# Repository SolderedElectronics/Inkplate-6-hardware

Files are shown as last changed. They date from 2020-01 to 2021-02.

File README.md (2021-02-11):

# Inkplate 6 Open Source Hardware files



Open Source Hardware (OSH) files for e-paper display Inkplate 6 can be found in this repo. Inkplate 6 is a powerful, Wi-Fi enabled ESP32 based six-inch e-paper display – recycled from a Kindle e-reader. Its main feature is simplicity. Just plug in a USB cable, open Arduino IDE, and change the contents of the screen with few lines of code. Learn more about Inkplate 6 on [Crowd Supply](https://www.crowdsupply.com/e-radionica/inkplate-6) or [official website](https://inkplate.io).

### Versions:
- v1.0. first, original version shipped to backers in 2020 and manufactured until January 2021.

### Misc
Inkplate 6 is available for purchase via:
- [e-radionica.com](https://e-radionica.com/en/inkplate.html)
- [Crowd Supply](https://www.crowdsupply.com/e-radionica/inkplate-6)
- [Mouser](https://hr.mouser.com/Search/Refine?Keyword=inkplate)
- [Pimoroni](https://shop.pimoroni.com/products/inkplate-6)

For all questions and issues, please open an issue or thread on [our forums](http://forum.e-radionica.com/en/).
For sales & collaboration, please reach us via [e-mail](mailto:kontakt@e-radionica.com).

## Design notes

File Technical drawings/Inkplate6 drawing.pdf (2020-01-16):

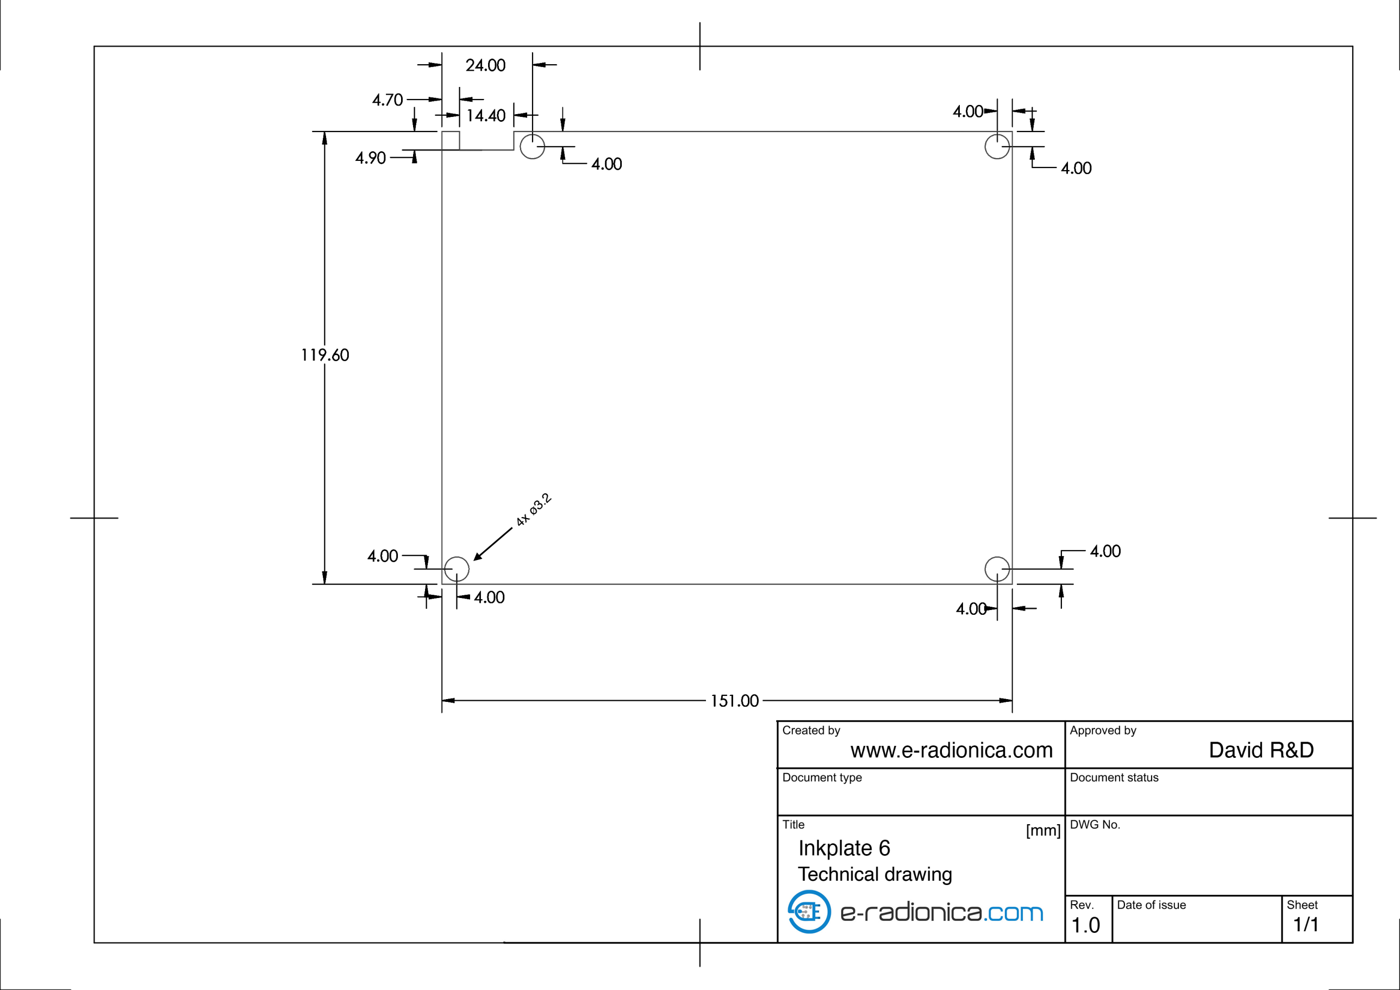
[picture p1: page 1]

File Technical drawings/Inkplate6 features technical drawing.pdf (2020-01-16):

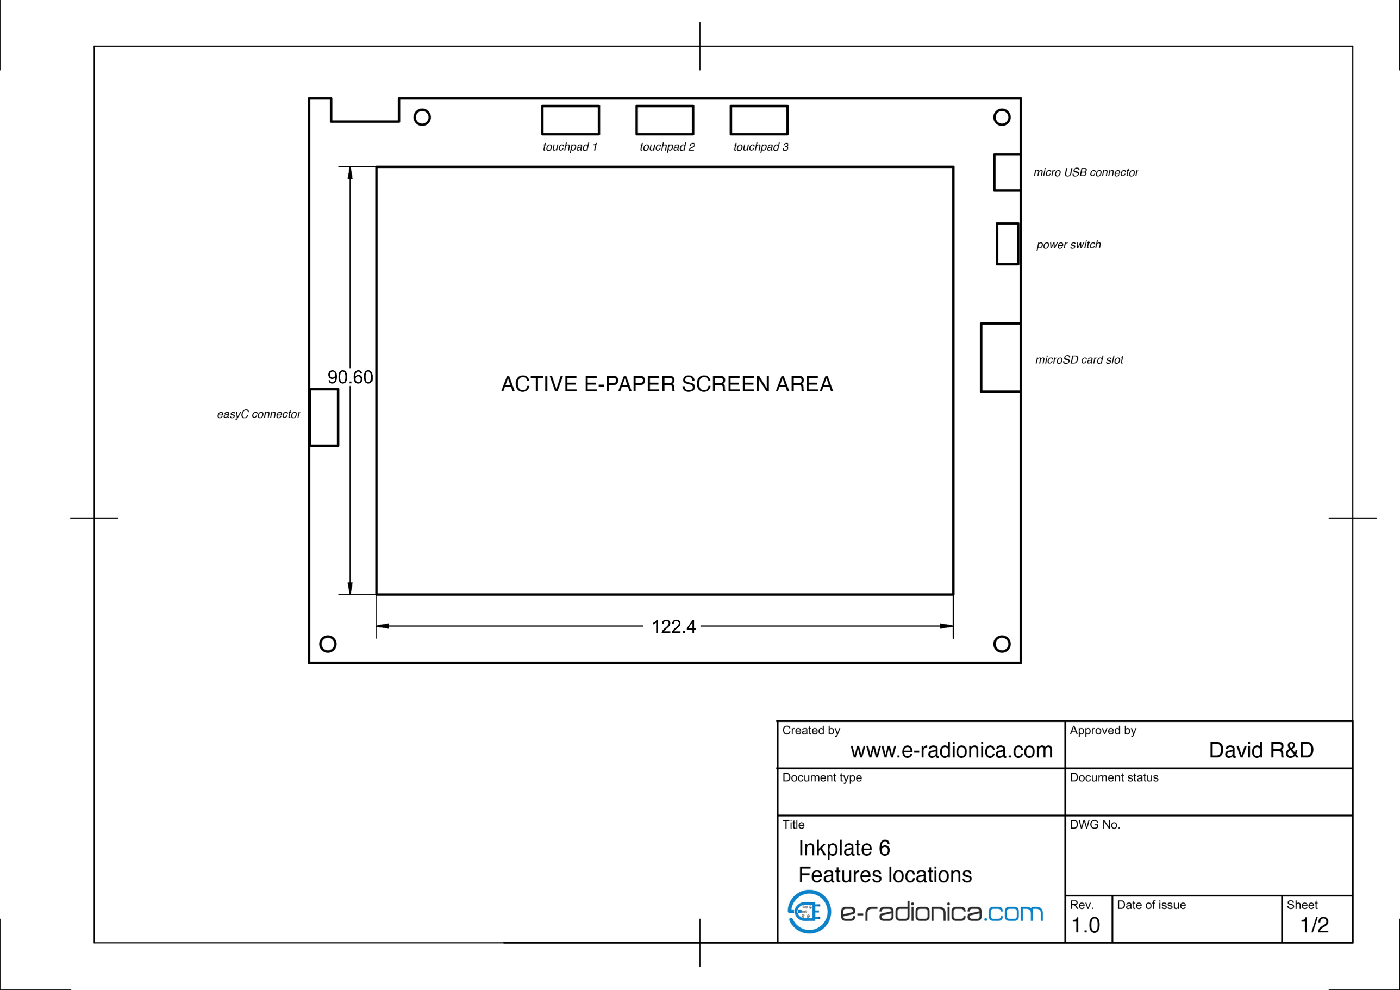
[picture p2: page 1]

122.4

90.60

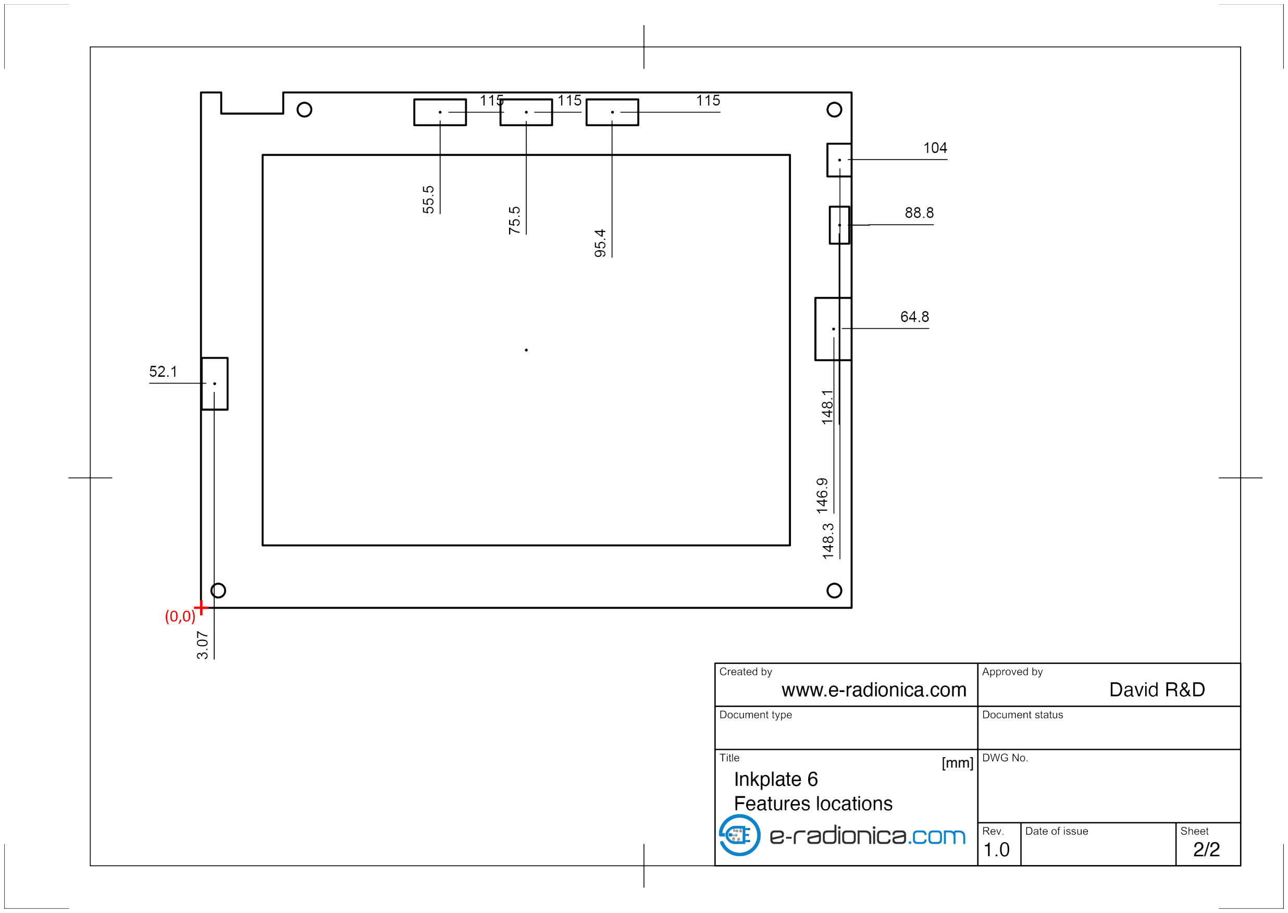
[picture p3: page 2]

(0,0)

+

[mm]

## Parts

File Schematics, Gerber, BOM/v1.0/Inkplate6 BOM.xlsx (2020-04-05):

Comment | Description | Designator | Footprint | LibRef | Quantity | Manufacturer PN
4u7-TMK212AB7475KG-T | CAPACITOR 0805 CERAMIC | C1, C2, C3, C4, C5, C6, C7, C10, C11, C12 | 0805C-GENERIC | 0805C-4U7-25V-X5R-TDK | 10 | TMK212AB7475KG-T
10uF-GRM188R61E106KA73J | CAPACITOR 0603 CERAMIC | C8, C9, C13 | 0603C-GENERIC | 0603C-10UF-10V-X5R-TDK | 3 | GRM188R61E106KA73J
100nF - AC0603KRX7R8BB104 | CAPACITOR 0603 CERAMIC | C14, C15 | 0603C-GENERIC | 0603C-100NF-25V-X7R-TDK | 2 | AC0603KRX7R8BB104
10nF-AC0603KRX7R8BB103 | CAPACITOR 0603 CERAMIC | C16, C19 | 0603C-GENERIC | 0603C-10NF-50V-X7R-MUR | 2 | AC0603KRX7R8BB103
2u2-GRM188R61E225MA12D | CAPACITOR 0603 CERAMIC | C17, C18 | 0603C-2U2 | 0603C-2U2-10V-X5R-TDK | 2 | GRM188R61E225MA12D
10UF | GENERIC CAPACITOR NON POLARISED 1206 | C20 | 1206C-GENERIC | 1206C-10U-35V-X7R | 1 | GENERIC
2u2 | CAPACITOR 0603 CERAMIC | C21, C27, C28, C39, C45 | 0603C-2U2 | 0603C-2U2-10V-X5R-TDK, 0603C-2U2-10V-X5R-TDK, 0603C-2U2-10V-X5R-TDK, 0603C-2U2-6V3-X5R-MUR, 0603C-2U2-10V-X5R-TDK | 5 | GENERIC
100nF | CAPACITOR 0603 CERAMIC | C22, C23, C24, C25, C26, C29, C30, C31, C32, C33, C34, C35, C40, C41, C49 | 0603C-GENERIC | 0603C-100NF-25V-X7R-TDK | 15 | GENERIC
27pF | CAPACITOR 0603 CERAMIC | C36, C37, C38 | 0603C-GENERIC | 0603C-27pF | 3 | GENERIC
68uF/6.3V | TANTALUM 3528 CAPACITOR | C42, C43 | C3528 | CAP3528 | 2 | GENERIC
100pF | CAPACITOR 0603 CERAMIC | C44 | 0603C-GENERIC | 0603C-100PF-50V-NP0-AVX | 1 | GENERIC
22pF | CAPACITOR 0603 CERAMIC | C46, C47 | 0603C-GENERIC | 0603C-22PF-50V-C0G-PAN | 2 | GENERIC
easyC | EASYC ECOSYSTEM JST CONNECTOR SMD FEMALE VERTICAL | CON1 | easyC | easyC | 1 | GENERIC
2PIN JST CONNECTOR | STANDARD LITHIUM BATTERY JST CONNECTOR | CON2 | JST_SMD_2P | JST_SMD_2P | 1 | GENERIC
USB_CONN | U-F-M5DD-Y-L | CON3 | USB_CONN | USB_CONN | 1 | U-F-M5DD-Y-L
BAS3010S-02LRHE6327 | DIODE SCHOTTKY 30V 1A TSLP-2 | D1, D2 | BAS3010S-02LRHE6327 | BAS3010S-02LRHE6327 | 2 | BAS3010S-02LRHE6327
BAT54-SOT23 | SINGLE SHOTTKY DIODE | D3, D4, D5, D6 | SOT23-123 | BAT54-SOT23 | 4 | BAT54
BAT20 | Schottky Diode SOD323 1A 23V | D8 | SOD323 | BAT20-SOD323 | 1 | BAT20J
AXT334124 | SMD CONNECTOR | DISP1 | AXT334124 | AXT334124 | 1 | AXT334124
GENERIC 500mA | GENERIC FUSE | F1 |  | FUSE-GENERIC | 1 | JK-NSMD050-13.2V
TPS65186 | IC PWR MGMT E INK 48VQFN | IC1 | TPS65186_QFN_48 | TPS65186RGZR | 1 | TPS65186RGZR
ESP32 WROVER | ESP32 WROVER WIFI MODULE | IC2 | ESP32_WROVER | ESP32WROVER | 1 | ESP32-WROVER
MCP23017 | I2C I/O Expander | IC3 | SOP28 | MCP23017 | 1 | MCP23017/SS
MCP73831 | LITHIUM BATTERY CHARGER | IC4 | SOT23-5_MCP | MCP73831 | 1 | MCP73831T-2ATI/OT
TTP223 | CAPACITIVE TOUCH CONTROLLER | IC6, IC7, IC8 | SOT95P285X126-6N_TTP223 | TTP223 | 3 | TTP223E-BA6
TPS3840PL27DBVR | RESET CONTROLLER | IC9 | TPS3840PH30DBVR | TPS3840PH30DBVR | 1 | TPS3840PL27DBVR
HYC77-TF09-200 | MICROSD CARD SLOT | K39 | HYC77-TF09-200 | HYC77-TF09-200 | 1 | HYC77-TF09-200
4.7uH | Inductor Power Chip Shielded Wirewound 4.7uH 20% 1MHz Ferrite 1.7A 96mOhm DCR 1515 Embossed T/R | L1 | LQH44PN4R7MP0_Inductor | LQH44PN4R7MP0L | 1 | LQH44PN4R7MP0L
2.2uH | FIXED IND 2.2UH 1.2A 108 MOHM | L2 | NR4012T2R2M_Fixed Inductor | NR4012T2R2M | 1 | NR4012T2R2M
LED0603 | LED 0603 SINGLE COLOR | LED1 | LED0603 | LED0603 | 1 | GENERIC
MTA50P01SN3 | P CHANNEL MOSFET - MTA50P01SN3 | Q1 | SOT23-GDS | BSS84 | 1 | MTA50P01SN3
MMBT2222 | MMBT2222 | Q2, Q3 | SOT95P237X110-3N | MMBT2222 | 2 | MMBT2222
CJ3407 | P CHANNEL MOSFET | Q4 | SOT23-GDS | BSS84 | 1 | GENERIC
NTC-NCP18X103F03RB | NCP18X103F03RB | R1 | 0603R-GENERIC | R0603-GENERIC | 1 | NCP18X103F03RB
43k-RC0603FR-0743KL | RC0603FR-0743KL | R2 | 0603R-GENERIC | R0603-GENERIC | 1 | RC0603FR-0743KL
1M | GENERIC RESISTOR 0603 | R3, R4 | 0603R-GENERIC | 0603R-1M | 2 | GENERIC
52k3-RC0603FR-0752K3L | RC0603FR-0752K3L | R5 | 0603R-GENERIC | R0603-GENERIC | 1 | RC0603FR-0752K3L
47k5-RC0603FR-0747K5L | RC0603FR-0747K5L | R6 | 0603R-GENERIC | R0603-GENERIC | 1 | RC0603FR-0747K5L
10K | GENERIC RESISTOR 0603 | R7, R8, R10, R11 | 0603R-10K | 0603R-10K | 4 | GENERIC
1K | GENERIC RESISTOR 0603 | R9, R12, R14, R16, R21, R22, R23, R27 | 0603R-1k | 0603R-1K | 8 | GENERIC
2K49 | GENERIC RESISTOR 0603 | R15 | 0603R-GENERIC | 0603R-2K49 | 1 | GENERIC
100K | GENERIC RESISTOR 0603 | R17, R19, R20 | 0603R-100K | 0603R-100K | 3 | GENERIC
0R - DNP | GENERIC JUMPER 0603 | R18 | 0603R-0R | 0603R-0R | 1 | GENERIC
510k | GENERIC RESISTOR 0603 | R24, R25 | 0603R-GENERIC | R0603-GENERIC | 2 | GENERIC
SMD Pushbutton | SMD PUSHBUTTON | SW1 | Pushbutton4x4 | TACT_SMD_SW | 1 | GENERIC
SPDT SWITCH THT | SPDT THT SWITCH 2A | SW2 | SPDT_SW | ONOFF_SW | 1 | 1
DMG2301L | P CHANNEL MOSFET | T1 | SOT90P240X110-3N | DMG2301L | 1 | DMG2301L-7
CH340G | USB-UART converter CH340G | U1 | SOP16 | CH340G | 1 | CH340G
TPS7A2633DRVR | ULTRA-LOW IQ VOLTAGE REGULATOR 500MA | U2 | TPS7A2633DRVR | TPS7A2633DRVR | 1 | TPS7A2633DRVR
12MHz | SMD CRYSTAL 12MHZ 3225 | Y1 | 3225_crystal | 3225-crystal | 1 | S3212000201080
ED060SC7 | E-PAPER DISPLAY 6INCH | - | ED060SC7 | ED060SC7 | 1 | ED060SC7

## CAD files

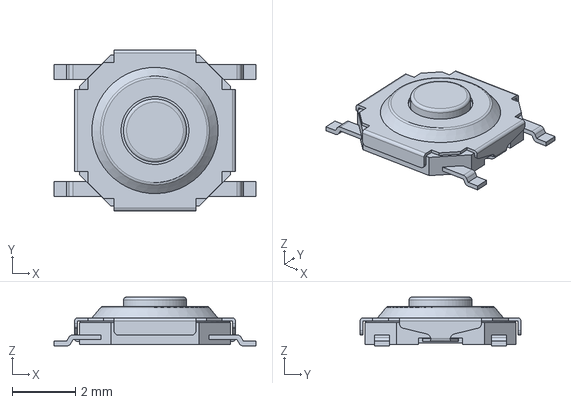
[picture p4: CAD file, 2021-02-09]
3D printable case/Guy's case/Electronics/KiCAD/Parts/3D/PTS526SK15SMTR2LFS.stp
6.40 x 5.10 x 1.55 mm

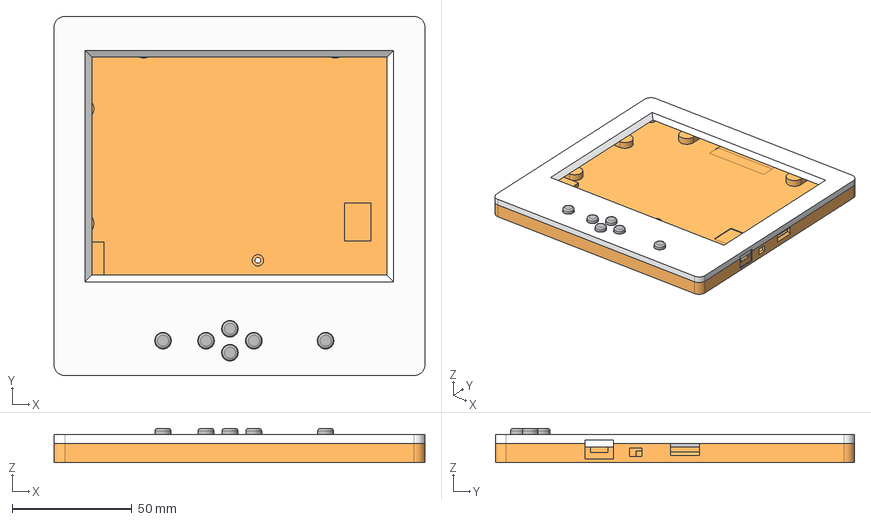
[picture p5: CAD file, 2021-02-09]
3D printable case/Guy's case/Mechanical CAD/Inkplate_6_Case_With_Mechanical_Buttons.step
155.2 x 150.2 x 14.3 mm
Inkplate_6_Case_Enlarged_Bottom
Button x 6
Inkplate_6_Case_Enlarged_Top
U1_1_601E0A63_5
U1_1_601E0A63
Pcb_dfda
U1_1_601E0A63_3
U1_1_601E0A63_4
U1_1_601E0A63_2
U1_1_601E0A63_1

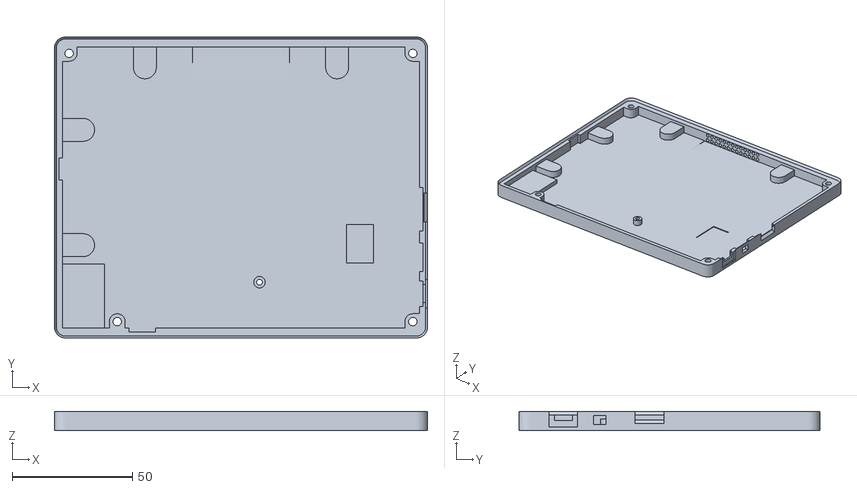
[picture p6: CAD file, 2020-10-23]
3D printable case/Original case/Inkplate_6_Case_Bottom.stl
155.2 x 125.2 x 8.00

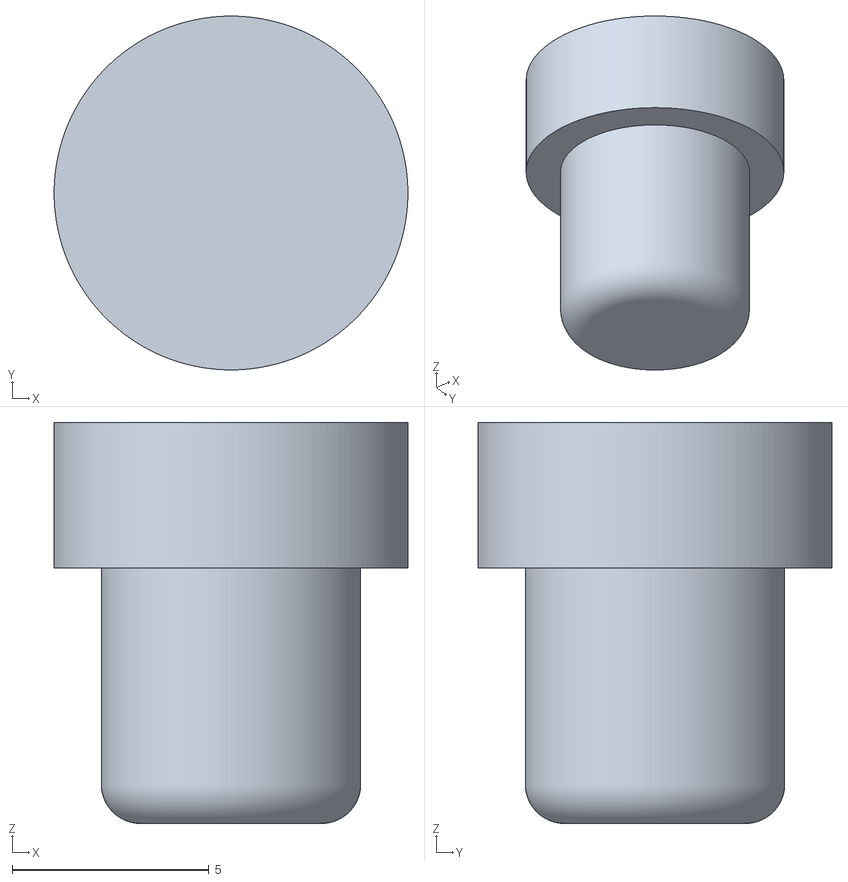
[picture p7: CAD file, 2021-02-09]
3D printable case/Guy's case/Mechanical CAD/Inkplate_6_Button.stl
9.00 x 9.00 x 10.2

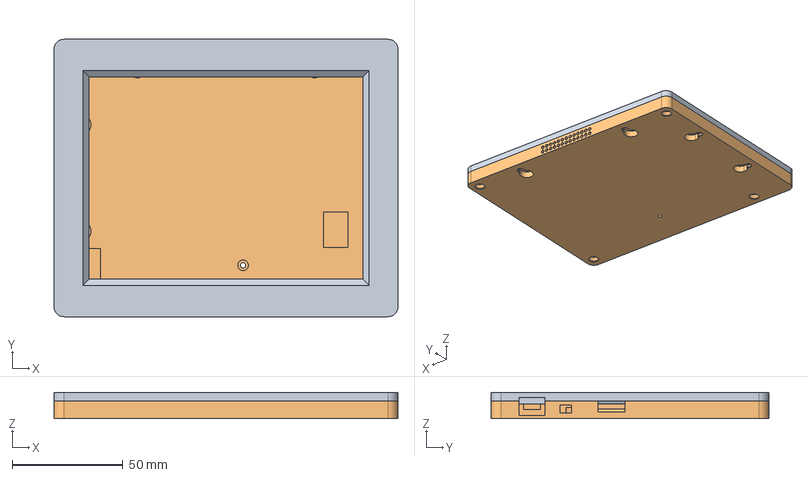
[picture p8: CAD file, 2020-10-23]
3D printable case/Original case/Inkplate_6_Case_v1_5.step
155.2 x 125.2 x 11.8 mm
Inkplate_6_Case_Top
Inkplate_6_Case_Bottom

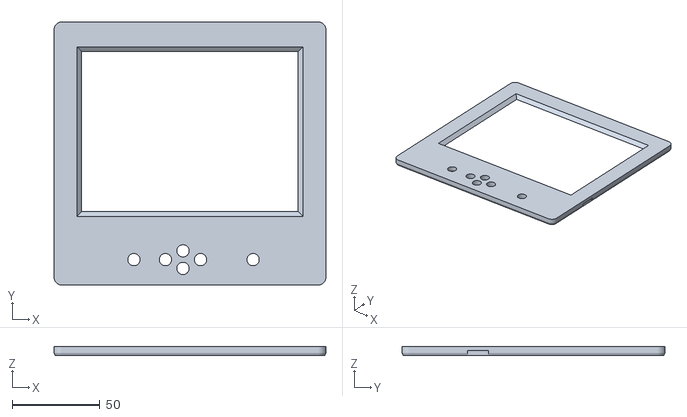
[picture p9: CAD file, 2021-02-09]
3D printable case/Guy's case/Mechanical CAD/Inkplate_6_Case_Enlarged_Top.stl
155.2 x 150.2 x 5.20

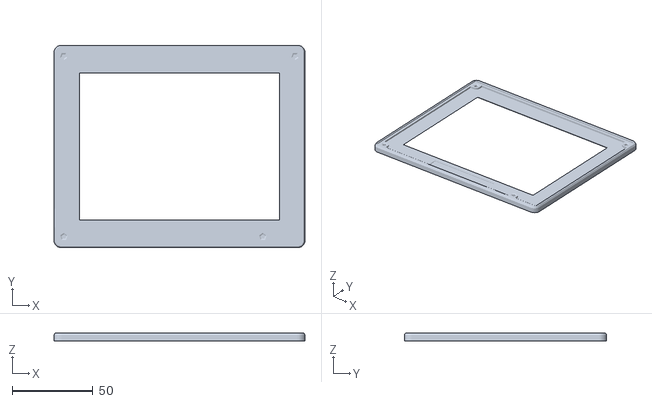
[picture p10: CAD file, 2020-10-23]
3D printable case/Original case/Inkplate_6_Case_Top.stl
155.2 x 125.2 x 5.20

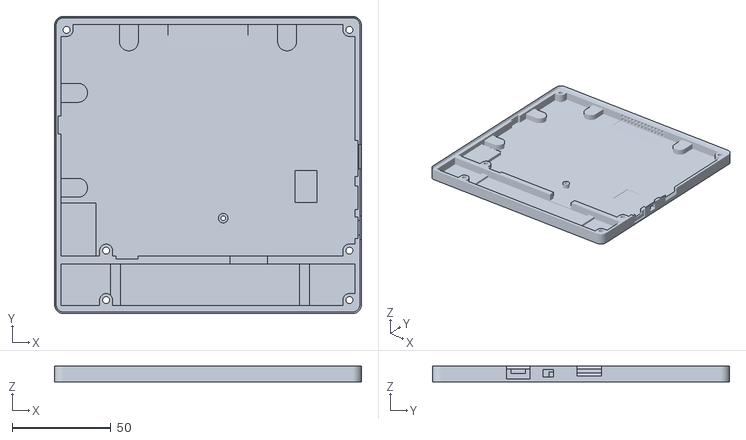
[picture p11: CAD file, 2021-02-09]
3D printable case/Guy's case/Mechanical CAD/Inkplate_6_Case_Enlarged_Bottom.stl
155.2 x 150.2 x 8.00

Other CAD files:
3D printable case/Inkplate_6_Case_v1_4.blend
3D printable case/Original case/Inkplate_6_Case_v1_5.f3d
3D printable case/Original case/OLD_Inkplate_6_Case_v1_4.blend

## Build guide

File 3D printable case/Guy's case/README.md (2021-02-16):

# InkPlate-6-Extended-Case

Find original Guy's work at [this repo](https://github.com/turgu1/InkPlate-6-Extended-Case).

This is a change to the current InkPlate-6 case to add a small electronic board with push buttons below the mainboard. To do it, I took the original design from e-Radionica and extended a side of it, so the original portion of the case remains unchanged. The `Mechanical CAD` folder contains the complete STEP format design as well as the STL files ready for 3D printing. The `Electronics` folder contains the Gerber files for the preparation of the pc-board, as well as the schematic in PDF. I have used **OnShape** and **KiCAD** to complete this project.

- For the STL files, dimensions are in millimeters. 
- Six buttons must be printed as well as the top and bottom casing. The buttons may have to be adjusted in size depending on the 3D printing results.
- The connection with the MCU23017 is done using wirewrap wires (or a flat cable) that are soldered at both ends using the following configuration (beware that the corresponding buttons numbers are inverted in the sequence):

```
   On the   |     On the     | Corresponding 
Buttons PCB | InkPlate Board |    Button
------------+----------------+---------------
            |                |
   Pin 1    |      GND       |
   Pin 2    |      GPB7      |      U6
   Pin 3    |      GPB6      |      U3
   Pin 4    |      GPB5      |      U5
   Pin 5    |      GPB4      |      U1
   Pin 6    |      GPB3      |      U4
   Pin 7    |      GPB2      |      U2
```

- The squared pad is pin 1.
- On the buttons' pc-board, there is no through-hole, just pads on the surface to solder the wires. This is to ensure that the board will remains flat at the bottom of it's location in the casing.
- The three touch pads on the InkPate-6 pc-board must be disabled, the corresponding signals from the MCU23017 must be diverted to the GPBx pin holes on the main pc-board. This is done by desoldering the current jumpers and soldering them back on the other side. They are located under the following labeling on the board: "Touch pads".
- The GPIOB I/O bits of the MCU23017 corresponding to the GPB2 through GPB7 pins must have their internal pull-up resistor enabled.
- The buttons' pc-board must be of a standard height (1.6 mm). This to ensure proper spacing for the printed buttons. The board must be 'glued' at the bottom of the main casing using two-sided scotch tape. An alternative would be using a very small amount of hot glue on the 4 corners on the top of the buttons' pc-board. This is to permit easy removal in case of problems. 
- The button switches' part number is C&K PTS526 SK15 SMTR2 LFS 5.2x5.2x1.5 mm. They are very common (For exemple, Mouser part # 611-PTS526SK15SMR2L, Digikey Part # CKN12221-1-ND, or other manufacturers equivalent). The 1.5 mm height is important to insure proper spacing for the printed buttons.

The original licensing from e-Radionica remains GPL-3 for their design as well as all supplied files in this project.

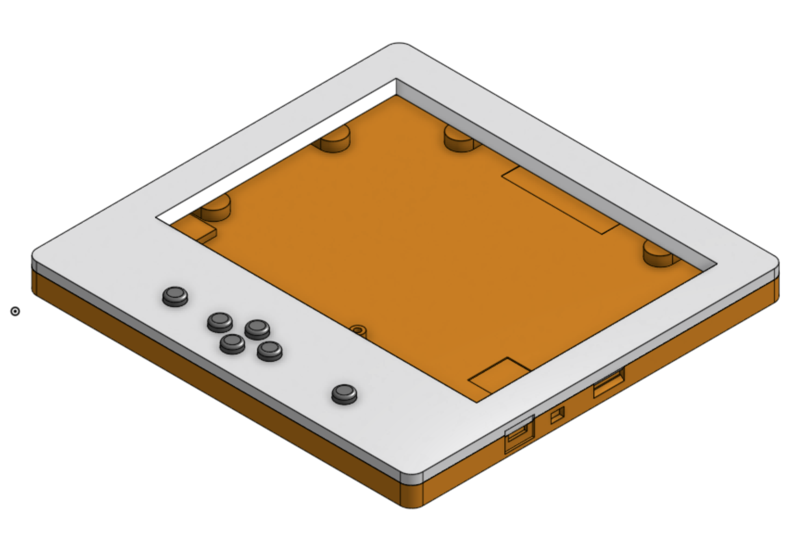
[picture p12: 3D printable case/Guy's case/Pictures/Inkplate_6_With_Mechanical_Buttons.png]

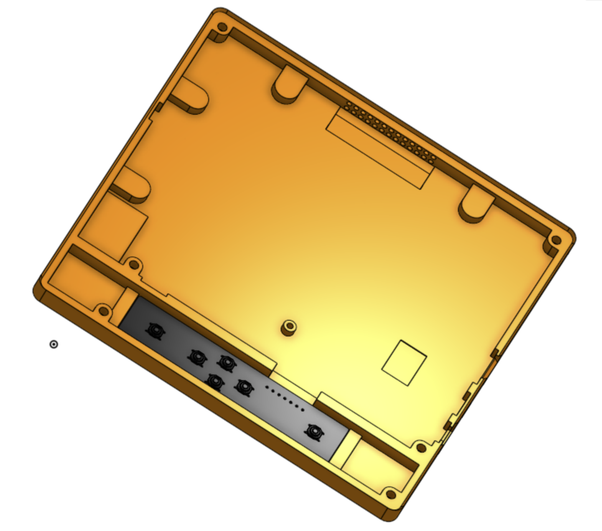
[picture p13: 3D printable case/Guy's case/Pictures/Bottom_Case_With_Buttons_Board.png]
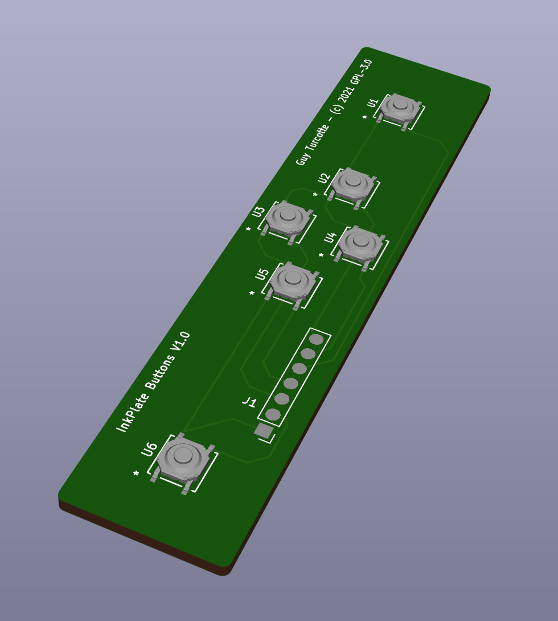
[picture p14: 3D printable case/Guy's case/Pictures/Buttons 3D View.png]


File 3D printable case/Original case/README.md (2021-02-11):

3D printable case. Printed in batches on Prusa MK3S(+) 3D printers, in PLA.

Screws: M3 x 10mm countersunk, 4 pieces

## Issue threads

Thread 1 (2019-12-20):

Feature request: 3D printable case

JustGitting, 2019-12-20:
Hi,

It is fantastic to see a free and open source e-reader using recycled parts. Well done!

Would you be able to add a basic 3D printable case design for Inkplate in the future?

Thanks!

davidzovko, 2019-12-22:
Thank you on praises, @JustGitting!

3D printable case is logical follow up, we will publish one on our crowdfunding campaign in the following weeks: https://www.crowdsupply.com/e-radionica/inkplate-6

.stl files will be added to this repo as well.

David

davidzovko, 2020-05-03:
Hey, files for the case has been added! We will update the 3D design file as it evolves.

Closed 2020-05-03.

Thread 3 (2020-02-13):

Sister project? The Open Book

JustGitting, 2020-02-13:
Hi,

It's exciting to see the Free-Software / Open Hardware movement gain momentum with the explicit aim of protecting our privacy.

I just found [The Open Book](https://github.com/joeycastillo/The-Open-Book)" project that is currently developing a open-source make it yourself e-reader. The specifications are lower, but the goals are just as high.

1) Would you be able to make a comparison between the Inkplate and The Open Book?

2) Would you consider helping each other as you both are working on essentially the same project? (I'm not affiliated, I just want both of your projects to succeed!)

Best wishes.

davidzovko, 2020-04-06:
Hey there, sorry for late reply!

The Open Book project is a great one. As my knowledge goes, it's made as open-source e-book reader. It has all you need to get started with e-book quickly, which Inkplate does not have. On the other hand, Inkplate has a simplicity to get you started with any kind of project which includes e-paper display, comparing to Open Book which is specialised.
So, it depends on the use case, but I see both product as a great contribution to open source community!

Of course, I have just sent a suggestion to the Open Book project owner. Let's see what he thinks :)

Thank you for the suggestion!
David

JustGitting, 2020-04-06:
No worries, I understand you and e-radioicacom have been busy!

Closed 2020-04-06.

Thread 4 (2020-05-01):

Idea: Type-C USB

craftbyte, 2020-05-01:
USB Type C connectors are being used more and more in the hardware industry (even RPi 4 has switched). It would be a logical idea for a new product like Inkplate to use USB-C instead of microUSB for longevity reasons (since unlike microUSB, with USB-C the cable deteriorates instead of the plug). Would it be possible to get an Inkplate v2 with a USB-C connector?

davidzovko, 2020-05-03:
Thanks for your suggestion, Anže. We agree and have already implemented USB-C for the future version.

Closed 2020-05-03.

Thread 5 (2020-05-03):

Please make actual source files available

sebastius, 2020-05-03:
Hi, this is not open-source hardware. I love the concept behind Inkplate and i'd love to contribute in the design. Sadly you've not published the actual source files, so i cannot contribute to your work. Please publish your sources, and also publish your iteration commits so we can see the design evolve and help out!

sebastius, 2020-05-09:
Oh another bit: you're not even including the component layout. So When you make these PCBs yourself, you have to reverse engineer the BOM+Schematic to figure out which bit goes where.

This is not open source hardware. Far from it even.

bbernhard, 2020-12-03:
I would also be interested in the eagle(?) files, in order to do some small modifications. Are there plans to opensource those files too? @davidzovko

dk5ra, 2020-12-05:
also interested! @davidzovko would be lovely

c5e3, 2020-12-05:
where is the pcb-layout source file of your cad software?

ziguana, 2021-05-29:
any updates on this?

SamantazFox, 2021-06-16:
Bump, I'd like to see the sources too!

Please provide Eagle/KiCad schematics and PCB design files, and BOM as CSV, not proprietary XLSX!

davidzovko, 2021-11-09:
Sorry not to publish the original source files. The files which we have are unavailable to be published publicly because of the software error which we have in Altium. We must redraw it in KiCad and afterwards, we will share it.

tiri, 2022-01-21:
I'd also like to see the source files publicly. Will they be released in the near future?

davidzovko, 2022-01-21:
Hi, yes, we are doing a redraw in KiCad and will publish them as soon as they are ready. We estimate about 2 months to get this done.

tiri, 2022-01-21:
Sounds awesome! Are you also going to publish also the 10" Inkplate source files?

davidzovko, 2022-01-22:
We are going to redo all board, incl. 10, in KiCAD and Soldered branding and release them here on our GitHub.

schroedi83, 2022-07-17:
Any update on this?

tommy-hartmann, 2023-01-16:
I bought the Inkplate6 just recently. I also printed the Case and and had to realize that it does not fit.
It would be nice to at least have a note in the Readme that there is a new version pf the board.

I am also interested which GPIO pin is used for the wakup button. Could we at least have a screenshot of the PCB Design?
Thanks!

c5e3, 2023-01-18:
i have the parts since more than 2 years, i think i'll just throw them away

ifadiga, 2023-01-22:
Hello,

Sorry for the problem with the wrong files for 3D model and schematics.

As David said before we working on new branding and doing all our boards in KiCad. We will be finished some of them for publishing on GitHub.

Next week we will have files for Inkplate 10. For the other Inkplate boards, I will put schematics and 3D models here in the comment until we publish all files.

ifadiga, 2023-01-25:
Hello
Here are the schematics for the four Inkplate that we finished. That are schematics for the new version of Inkplate. We fixed some things on it, but it is similar to the old one. If you need old schematics for some reason, tell me, and I can send you a PDF file. When asked for a schematic, write which GPIO expander you have on board and which branding (e-radionica or Soldered).

[Soldered Inkplate 10 Schematics.pdf](https://github.com/SolderedElectronics/Inkplate-6-hardware/files/10498529/Soldered.Inkplate.10.Schematics.pdf)
[Soldered Inkplate6 Schematics.pdf](https://github.com/SolderedElectronics/Inkplate-6-hardware/files/10498530/Soldered.Inkplate6.Schematics.pdf)
[Soldered Inkplate 6COLOR Schematics.pdf](https://github.com/SolderedElectronics/Inkplate-6-hardware/files/10498531/Soldered.Inkplate.6COLOR.Schematics.pdf)
[Soldered Inkplate 6PLUS Schematics.pdf](https://github.com/SolderedElectronics/Inkplate-6-hardware/files/10498532/Soldered.Inkplate.6PLUS.Schematics.pdf)

We are working on some details for the 3D case, and when finished, I will send it to you.

ifadiga, 2023-02-07:
We published files for our new Inkplate 10 board. You can see them on the [link ](url=https://github.com/SolderedElectronics/Soldered-Inkplate-10-hardware-design)

olalid, 2023-06-02:
I have just printed 3D case from files in the repository only to realise that it is not at all compatible with the board I just bought. The mechanical drawings are also not for the board I bought.
When can we expect correct drawings and/or 3D model to be available?

ifadiga, 2023-06-06:
Hello,
Sorry for the wrong file for Inkplate.

We working on the process for updating hardware files on GitHub and I hope that it will be done this week then all files will be available on our GitHub.

rosspointon, 2023-12-20:
@ifadiga - is there any update on the availability of the updated Inkplate 6 case 3d printable design? I just bought a replacement board without an enclosure thinking I could re-use my existing case but the hardware size/layout has changed.

rosspointon, 2023-12-20:
actually this library looks like it has the updated versions - its just quite hidden - https://github.com/SolderedElectronics/Soldered-Inkplate-6-hardware-design/

ifadiga, 2024-03-12:
Hello,

We've recently changed our storage system, and as a result, we don't yet have a repository for Inkplate 5. Due to these changes, I can't determine when the automatic repository setup will function as it did before.

For now, I'll send all the files in a zip file.
[Soldered Inkplate 5.zip](https://github.com/SolderedElectronics/Inkplate-6-hardware/files/14569012/Soldered.Inkplate.5.zip)

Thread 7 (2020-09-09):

Wifi on battery power not working

tobias--, 2020-09-09:
I am experiencing issues with my inkplate whenever I try to connect to a wifi and power the inkplate using a LiPo battery (3.7V, 1000mAh). It seems that starting up wifi momentarily draws too much current which triggers the battery protection circuit. When I try to measure the current it seems to peak at 1A, the capacity of the battery. This leads me to believe that powering Wifi might be drawing more the 1A. Is this to be expected by the ESP32?

When I connect power the inkplate using USB on startup and then disconnect USB after a wifi connection has been established, the battery is able to power the board and wifi transmissions just fine.

To rule out a faulty protection circuit/battery a different battery with larger capacity is already in the mail. However, I am wondering whether this is a known issue, a problem with my inkplate or the way I try to connect to a wifi.

BornaBiro, 2020-09-09:
Yes, ESP32 can draw very high current spikes, while connecting to a WiFi network, especially if you have bad WiFi reception. In fact, in ESP32 datasheet minimal power supply current requirement is 500 mA, which means that ESP32 can draw even more. Ffor some weird reason, WiFi radio while powering up can draw few amps of current (2A peaks in duration of 100uS). Also, there is epaper that itself does not consume any energy while keeping content on the screen, but when it refreshes, it can draw very high current.

In our testing, @3.6V Inkplate was consuming about 0.8A to 1.5A peak while refreshing the screen and connecting to WiFi network, which is more than 1A that you measured, so this is perfectly fine.

We highly advise you to use a good 18650 Lithium battery for Inkplate, or if you really wanna use these small LiPo batteries, you can try to use it with supercap with low ESR in parallel with the battery.

davidzovko, 2020-09-15:
If there are no more comments, we will close this issue.

tobias--, 2020-09-16:
Thank you for looking into this!

I neither had luck with a new 2000mAh LiPo battery. It seems to connect briefly to a WiFi but immediately restarts. And I did not even draw anything on the display. Is there any way to completely turn off the display (or other components on the board) in order to separate WiFi and display action?

1.5A peak seems high for a device that is based on ESP32. Do you know what causes this and are there any plans on optimizing Inkplate to be run on battery power?

You recommend a specific LiPo battery for inkplate with 1200mAh. But at the moment I doubt that it will work in combination with WiFi. Maybe you could mention this in the documentation somewhere.

davidzovko, 2020-09-26:
All our testing was done using the [mentioned](https://e-radionica.com/en/li-ion-battery-1200mah.html) 1200mAh battery. It is not everything in the capacity, some batteries are able to source larger currents comparing to others. Thus, 1200mAh might work while 2000mAh might now.

But we would definitely would like to look more deeply into this issue. Can you give us a link to where you have bought your 2000mAh battery?
Could you share the code you are using?

We are definitely looking to reduce "power-hungry" peaks that Inkplate has and providing that info will be helpful in reaching that.

Closed 2020-09-15.

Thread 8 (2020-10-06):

New 3D printable case

jf1452, 2020-10-06:
Whilst I like the design of the other 3D printable case; I did have some difficulties with it not having space for a battery, and for my poorly aligned printer, I has some issues joining the front and the back which gave me an opportunity to learn how to use FreeCad.

I attach my alternative new designs in FreeCad and stl formats for others to use; to assemble you just need some 10mm plastic standoffs. unfortunately, the holes are not quite in the right place (I think the technical drawings are not quite correct for hole and port alignment) I overcame this by drilling the PCB holes to 3.5mm which allowed it to fit.

[3D printable case.zip](https://github.com/e-radionicacom/Inkplate-6-hardware/files/5335798/3D.printable.case.zip)

davidzovko, 2020-10-11:
Hello, yes indeed, the printer really needs to be really nicely aligned to fit top and bottom pieces.

If you can fix the model to fit the board without drilling the holes, we will add your design to the git into community designs folder so anyone can use it.

Thanks!

Closed 2020-10-23.

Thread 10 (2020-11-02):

Powers up fine from USB, but not from battery

jf1452, 2020-11-02:
I'm working on an OpenWeather display based on the code you provided as an example.

I have tried a smaller battery (the same part number that you supply), and the much larger battery in the photo which was salvaged from a tablet with a broken screen. But the unit will not start on battery alone; it runs fine from USB.

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

The trace above is at the connector on the Inkplate, you can see the nominal 4.2V rail which has disturbances to 4.04V (probably when starting the WiFi; nothing jumps out as a major concern here. I have also probed the 3V3 rail on the Inkplate and that also stays steady.

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

The image is of the battery; although used, it still has good charge capacity and able to drive a 1A load.

For interest purpose, here's a photo of my OpenWeather display; still more work to be done before I release the code, but I have uploaded what I've done so far to git.

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

Any idea on what the issue is and why I cannot power InkPlate from a battery?

BornaBiro, 2020-11-04:
Hello jf1452!

I'm sorry to hear that you have issues with your Inkplate.

We investigated this issue and it turns out that it is not a power issue, rather it's an issue related to reset IC. Reset IC is responsible for proper power up and power down of Inkplate. This IC has a manual reset input, which is connected to the reset pushbutton. For some reason, when Inkplate is powered from the battery there is enough noise on trace that connects reset pushbutton to the reset IC MR pin causing reset IC to reset whole board.
There are two solutions to this problem:
 - Connect 10k - 100k pull up resistor on reset IC MR pin (reset IC is small 5 pin IC near epaper connector and MR (manual reset) is 4th pin on this IC. Pull up should be connected to 3.3V rail.
 - There is a small SMD 100nF capacitor near reset pushbutton. Add 2.2 - 4.7uF capacitor parallel to it.

davidzovko, 2020-11-05:
Correct, as Borna suggested, with photo: http://forum.e-radionica.com/en/viewtopic.php?f=22&t=288#p274

We will fix this in the next HW revision.

jf1452, 2020-11-05:
Yes, the extra capacitor and / or the resistor fixes the issue.

As an extra note, when powered from USB, I also experienced frequent resets, originally I thought I had a software issue but it has also now been resolved so I suspect MR was being applied from any power source.

Zylanx, 2023-11-05:
> Correct, as Borna suggested, with photo: http://forum.e-radionica.com/en/viewtopic.php?f=22&t=288#p274
>
> We will fix this in the next HW revision.

The forum link is dead, is there any information in the fix?

Closed 2020-11-05.

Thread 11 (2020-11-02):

Wifi antenna enhancement

jf1452, 2020-11-02:
Not so much of an issue, but more of a recommendation for an enhancement.

The stock PCB wifi antenna on the ESP32 does not provide very good reception, I modified mine by changing the antenna link and hardwiring an old router antenna. (Move R15 to position R14)

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

I stripped the antenna from the plastic case to make it fit better into the case and glued it to the side.

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

If I had a spare SMA connector I would have soldered that to the board and used the plug / socket rather than my bodge of hard wiring.

jf1452, 2020-11-02:
Closed as this one was an accidental duplication due to a browser crash.

Closed 2020-11-02.

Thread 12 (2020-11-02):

Wi-Fi antenna enhancement

jf1452, 2020-11-02:
Not so much of an issue, but more of a recommendation for an enhancement.

The stock PCB Wi-Fi antenna on the ESP32 does not provide very good reception, I modified mine by changing the antenna link and hardwiring an old router antenna. (Move R15 to position R14)

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

I stripped the antenna from the plastic case to make it fit better into the case and glued it to the side.

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

If I had a spare SMA connector I would have soldered that to the board and used the plug / socket rather than my bodge of hard wiring.

davidzovko, 2020-11-05:
Thanks on your report. I would say this mostly depends on your WiFi setup and signal strength. This is the first report about WiFi reception issues regarding Inkplate that I see.

What you have done is the correct was to add an external antenna and can be done in cases when reception is weak. We will add this info to the official documentation soon.

Closed 2020-11-05.

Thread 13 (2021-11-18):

Having trouble getting battery to charge

vcazan, 2021-11-18:
Hello, I have 3 inkplate devices here with standard off the shelf 3.7v li-ion batteries plugged in and I cannot get any of them to charge. Is there any special software definitions that must be set for the charger to be enabled? The LED charging light does not turn on when the micro usb cable is plugged in to the board. Thanks in advance for the help.

davidzovko, 2021-11-18:
Hey, which battery do you use?

Did you confirm the polarity of the battery matches the polarity on the board connector?

vcazan, 2021-11-18:
Using this battery currently and I can confirm the polarity of the connector is correct.
https://www.amazon.ca/gp/product/B091YMWC72/ref=ppx_yo_dt_b_asin_title_o06_s00?ie=UTF8&psc=1

BornaBiro, 2021-11-22:
Can you check if there is any voltage on Inkplate JST connector when there is no battery connected and Inkplate board is connected to the USB power supply?

Can you also check if there is any power on Inkplate board?

ADeadPixel, 2022-07-12:
I am having the same issue with my Inkplate 6PLUS. I do measure voltage across the JST connector (~4.82v usb only & ~3.81v batt plugged in) when it is plugged in via usb. I have verified that the polarity is correct (I needed to flip my battery wires).

What is odd is when I test the charge LED for voltage (~.3v usb only & ~.4v batt plugged in) it very briefly and very dimly lights up. Now when I test for continuity and touch both sides of the charge LED it lights up very brightly (~1.78v usb only & ~1.78v batt plugged in). This leads me to think that maybe the trace or connection is faulty or something else is going on.

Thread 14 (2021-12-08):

Can't program it anymore

jf1452, 2021-12-08:
Working fine since all the mods. I decided to update the software and try to reload it after all Arduino libraries have been updated, but I keep getting:

esptool.py v3.0-dev
Serial port COM4
Connecting........_____....._____....._____....._____....._____....._____....._____

A fatal error occurred: Failed to connect to ESP32: Timed out waiting for packet header
A fatal error occurred: Failed to connect to ESP32: Timed out waiting for packet header

I've tried disconnecting the battery, holding reset during power up, switching it on / off. Pressing reset when trying to program but still unable to upload new firmware.

Any ideas / tricks to upload new code?

TedMGN, 2022-08-15:
Hi,
I have the same issue since few days.
I developed projects for the Inkplate since December 2020. It was not a problem to upload new sketch to my Inkplates.

Yesterday I tried to upload a new sketch to my second Inkplate and get an error while uploading.
```
Sketch uses 1558882 bytes (49%) of program storage space. Maximum is 3145728 bytes.
Global variables use 62024 bytes (18%) of dynamic memory, leaving 265656 bytes for local variables. Maximum is 327680 bytes.
esptool.py v3.0-dev
Serial port /dev/ttyUSB0
Connecting........_____....._____....._____....._____....._____....._____.....____An error occurred while uploading the sketch
_

A fatal error occurred: Failed to connect to ESP32: Timed out waiting for packet header
```
I tried the version before (1.0.0) of Inkplate Boards, but I got the same error.
```
Sketch uses 1539638 bytes (48%) of program storage space. Maximum is 3145728 bytes.
Global variables use 58760 bytes (17%) of dynamic memory, leaving 268920 bytes for local variables. Maximum is 327680 bytes.
esptool.py v2.6-beta1
Serial port /dev/ttyUSB0
Connecting........_____....._____....._____....._____....._____....._____.....____An error occurred while uploading the sketch
_

A fatal error occurred: Failed to connect to ESP32: Timed out waiting for packet header
```
But with both versions I see my logging on the serial interface. It means the communication works fine.
And the other point is, my Inkplate makes a reset after I got the error. In my feeling the communication also works.
I also tried to remove the battery or switch on the reset while uploading. Nothing helps.

Then I tried to upload the sketch to my first Inkplate.
With this Inkplate I can upload new sketches with both versions of Inkplate Boards.
I found many different entries in the web to fix this issue. But this entries describes other boards not the Inkplate.

Do you have any ideas to fix that problem?
Thanks in advance.
Detlef

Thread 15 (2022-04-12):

LED Charge not working -> question

maltejahn, 2022-04-12:
Hi,

the LED charge indicator doenst do anything. If i am right, the little green dot of the LED should face "away" from the resistor. But on m bought pcb the dot faces towards the 1k resistor. -> Inkplate 6
Ok, you cant fix this from far away.

But, i also have trouble to read out the "nearly" correct voltage. If I use your example Inkplate_Battery_Voltage_And_Temperature.ino I get for e.g. 4.18V at the connector of the LiPO a shown voltage of 4.61 V. I read about a software bug related to the mosfet. But I think this should already be implemented since this problem was fixed in late 2020?

I now would like to get the raw ad values to correct it myself. But i wasnt able as the needed functions are implemented in the inkplate library. Is it possible to add a "double System::readBattery_raw() function in the system.cpp. I could do it on my own, but with the next update this will be probalby gone.

And one last question. What is the minimum Voltage, measured at the battery connector, the Display will work. The ESP should work at a minimum voltage of 3.0 V. The Texas LDO has a drop of 280 mV @ 250 mA.
So, the Display should work fine till the battery goes down to about 3.3 V? I am looking where i should set my "go charge me" Information

BornaBiro, 2022-04-13:
Hello maltejahn!

LED is properly rotated on all our Inkplate boards as far as we know. What can happen is that LED in the reel can be rotated the opposite way and really we can't do much about it (because the pick and place machine doesn't look for LED orientation on the camera). We are really sorry about that.

About the issue with reading battery voltage; it's not a problem with the MOSFET switch, it's the inaccuracy of ESP32 ADC. There are many topics about that issue on esp32 forum and their github page like [this](https://esp32.com/viewtopic.php?t=13089) and [this](https://github.com/espressif/arduino-esp32/issues/1804). Long story short, every Inkplate board needs to be [calibrated](https://github.com/e-radionicacom/Inkplate-Arduino-library/blob/master/examples/Inkplate6/Advanced_Inkplate_Features/Inkplate_Battery_Voltage_And_Temperature/Inkplat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).

For RAW ADC readings, you can see how [readBattery() functions](https://github.com/e-radionicacom/Inkplate-Arduino-library/blob/master/src/include/System.cpp#L102) works and you can implement this ADC RAW function yourself outside the Inkplate library so it doesn't break or disappear in the next library update. Just before reading, enable the MOSFETs for the voltage divider, measure it and then disable the voltage divider. :)

Inkplate should work down to 3.1V in out testing (with a good battery that can supply at least 1A of current) without the WIFI, and with the WiFi on is 3.3V.

maltejahn, 2022-04-13:
Hi,

and thanks for you reply.

I  already tried to do my on raw reading, but im stuck with the way to do it:

/include/myADC.h
`#include "Arduino.h"
#include "SPI.h"
#include "time.h"
#include "Esp.h"
#include "Wire.h"

#include "../.pio/libdeps/esp32/InkplateLibrary/src/include/defines.h"
#include "../.pio/libdeps/esp32/InkplateLibrary/src/include/System.h"

#include "../.pio/libdeps/esp32/InkplateLibrary/src/include/Mcp.h"

double myReadBattery();`

/src/myADC.cpp
`#include "../include/myADC.h"
double myReadBattery()
{
    pinModeInternal(MCP23017_INT_ADDR, mcpRegsInt, 9, INPUT);
    return (double(1));

}`

I only added these lines, because i get the error that pinModeInternal wasnt found.

maltejahn, 2022-04-24:
I close this because it's related to the library usage.

I wasn't able to get the myADC function out of system.cpp without errors. So the system.cpp is still modified and will be overwritten when I update all files.

But now I did some measurements (ad raw value - > corresponding voltage) and it fits quite well in the range of interest.

Some suggestions for an hardware revision:
- a jumper and two solder pads to get a ampere meter in line with the battery
- solder pads for the status led to be able to place it anywhere
- or be able to connect the status pin to the mcp to read if it's charging or done

Closed 2022-04-24.

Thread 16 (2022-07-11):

microSD card slot measurement is incorrect

marmphco, 2022-07-11:
The distance measurement for the microSD card reader in https://github.com/e-radionicacom/Inkplate-6-hardware/blob/master/Technical%20drawings/Inkplate6%20features%20technical%20drawing.pdf is 64.8mm, but it should be 68.4mm.

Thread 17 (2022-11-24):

6Color specs not available anywhere

omnigrok, 2022-11-24:
Hi,

I've been looking around for the design files for the 6Color, and can't find them. Most things I've found for other board (6Plus, 10) mention the MCP23107 IO expander, but the back of my board labels those GPIO pins as being behind a PCAL6416AHF expander instead, so I can't rely on those specs.

Do you have the actual specs for the 6Color available somewhere?

Thanks

ifadiga, 2023-07-10:
Hello,
Sorry for the late response, we were working on the documentation and now we published files for Inkplate 6Color.
https://github.com/SolderedElectronics/Soldered-Inkplate-6COLOR-hardware-design

omnigrok, 2023-07-10:
Thank you!

Closed 2023-07-10.

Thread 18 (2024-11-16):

Original 6COLOR Drawings/Case Model

GiantSox, 2024-11-16:
Hi there!

Are the drawings and case models for the original 6COLOR (the one with the buttons at the bottom) still available anywhere? Google leads me to https://github.com/SolderedElectronics/Soldered-Inkplate-6COLOR-hardware-design which doesn't seem to exist anymore.

rsoric, 2024-11-19:
Hi @GiantSox ,

thanks for your questions, I've asked our R&D team about this. We never created a 3D printed case for a 6COLOR model with touchpads. So, there are no cases for those older models, only the newer ones. I could only provide you with the schematic if that's in any way useful to you.

-Rob

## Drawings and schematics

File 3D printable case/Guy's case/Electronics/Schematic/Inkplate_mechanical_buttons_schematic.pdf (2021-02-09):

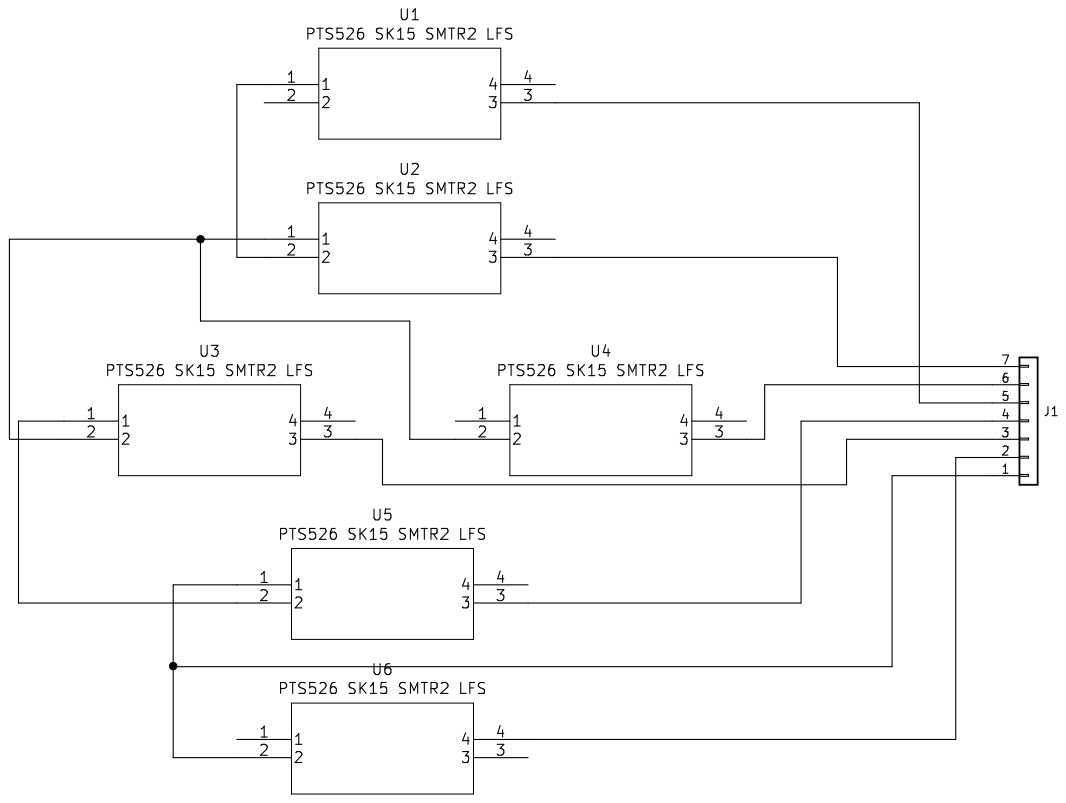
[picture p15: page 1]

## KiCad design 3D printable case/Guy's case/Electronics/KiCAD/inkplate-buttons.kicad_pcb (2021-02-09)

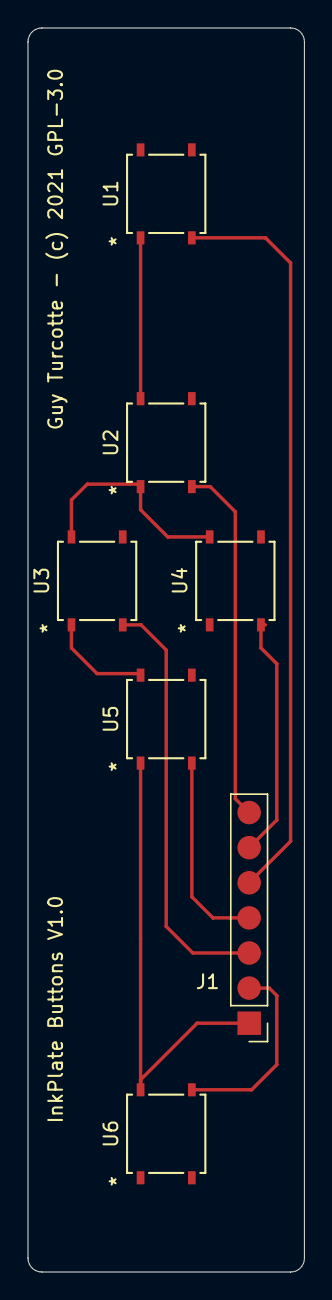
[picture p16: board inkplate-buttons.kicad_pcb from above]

Board: 2 copper layers, 20.0 x 90.0 mm, 7 parts (0 on the bottom side), 10 nets.

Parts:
J1: J1; PinHeader_1x07_P2.54mm_Vertical
U1: U1; PTS526 SK15 SMTR2 LFS
U2: U2; PTS526 SK15 SMTR2 LFS
U3: U3; PTS526 SK15 SMTR2 LFS
U4: U4; PTS526 SK15 SMTR2 LFS
U5: U5; PTS526 SK15 SMTR2 LFS
U6: U6; PTS526 SK15 SMTR2 LFS

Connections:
unnamed: J1.1, U5.1, U6.2
unnamed: J1.2, U6.4
unnamed: J1.3, U3.3
unnamed: J1.4, U5.3
unnamed: J1.5, U1.3
unnamed: J1.6, U4.3
unnamed: J1.7, U2.3
unnamed: U1.1, U2.2
unnamed: U2.1, U3.2, U4.2
unnamed: U3.1, U5.2

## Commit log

2019-12-15 Add proto v4 schematics
2019-12-15 Add Proto v4 BOM
    [Inkplate 6 Proto v4 BOM.xlsx]
2019-12-15 Add prototype v4 gerbers
2020-04-05 Upload production version files
    Uploaded and updated the new production files for Inkplate 6, including schematics, BOM and gereber files.
    Reoganised the repo a bit.
    [Inkplate 6 Proto v4 BOM.xlsx, Inkplate6 BOM.xlsx]
2020-05-10 Add the newest version
    [Inkplate_6_Case_Bottom.stl, Inkplate_6_Case_Top.stl]
2020-05-18 add blend file
    [Inkplate_6_Case_v1_3.blend]
2020-07-31 Add IO to case
    [Inkplate_6_Case_Bottom.stl, Inkplate_6_Case_v1_3.blend, Inkplate_6_Case_v1_4.blend]
2020-10-19 STEP format case
    [Inkplate_6_Case_Bottom.stl, Inkplate_6_Case_Top.stl, Inkplate_6_Case_v1_5.step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]
2020-10-19 Add Fusion360 file
    [Inkplate_6_Case_v1_5.f3d]
2021-02-09 Add Guy's case
    [Inkplate_6_Button.stl, Inkplate_6_Case_Bottom.stl, Inkplate_6_Case_Enlarged_Bottom.stl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]
2021-02-11 Add versioning folder
    [Inkplate6 BOM.xlsx]
2021-02-16 Update README for Guy case

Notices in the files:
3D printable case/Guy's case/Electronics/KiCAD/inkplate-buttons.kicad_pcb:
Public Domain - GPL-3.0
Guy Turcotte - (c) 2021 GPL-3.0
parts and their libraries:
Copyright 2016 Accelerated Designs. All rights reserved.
